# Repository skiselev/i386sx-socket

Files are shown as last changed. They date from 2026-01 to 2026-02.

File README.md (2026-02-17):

# i386sx-socket
386SX Universal Socket Adapter for the [Alsea River 386SX Motherboard](https://github.com/skiselev/mb386sx-rc2016)

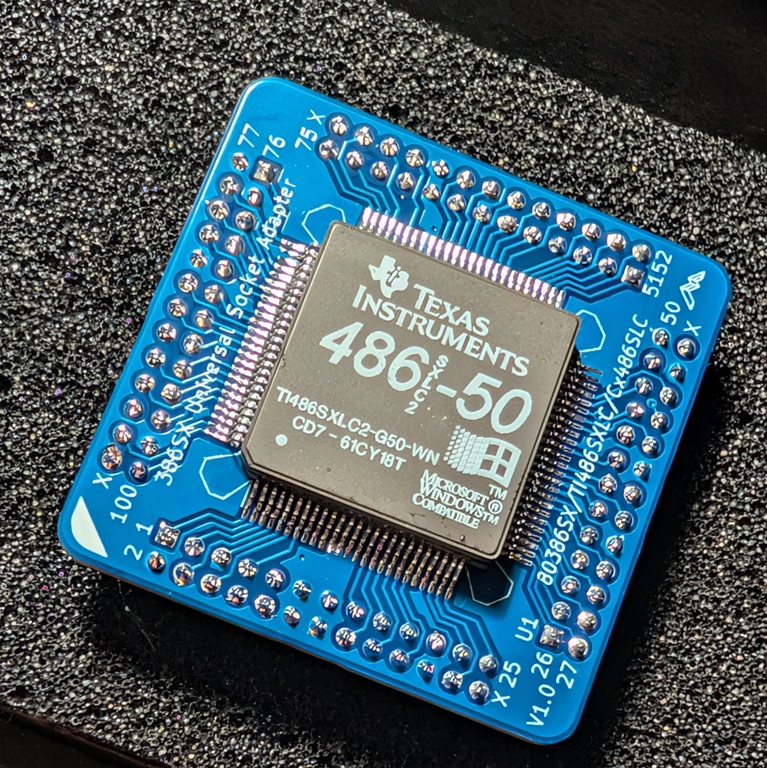
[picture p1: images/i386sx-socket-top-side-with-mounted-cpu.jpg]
386SX Universal Socket Adapter Assembled Board


## Hardware Documentation

### Schematic and PCB Layout

* [Schematic - Version 1.0](KiCad/i386sx-socket-Schematic-1.0.pdf)
* [PCB Layout - Version 1.0](KiCad/i386sx-socket-Board-1.0.pdf)

### Jumpers

#### JP1, JP2 - Bypass the 3.3V Voltage Regulator

Position         | Description
-----------------|--------------------------------------------------------------------------------------------------
Closed (default) | 5V CPU: 5V from the socket is connected to the CPU VCC pins, bypassing the 3.3V voltage regulator
Open             | 3.3V CPU: CPU VCC pins are connected to the 3.3V voltage regulator

#### JP3 - Connect Pin 45 to VCC

Position         | Description
-----------------|--------------------------------------------------------------------------------------------------
1-2              | 5V CPU: Socket pin 45 is connected to the CPU pin 45
Open             | 3.3V CPU: CPU pin 45 is connected to 5V (VCC5 for the 3.3V CPUs)

### Bill of Materials

#### Version 1.0

[386SX Universal Socket Adapter project on Mouser.com](https://www.mouser.com/Tools/Project/Share?AccessID=3e806c1828) - View and order most components except of the CPU, and the PCB.

Component type     | Reference | Description                                          | Quantity | Possible sources and notes 
------------------ | --------- | ---------------------------------------------------- | -------- | --------------------------
PCB                |           | 386SX Universal Socket PCB - Version 1.0             | 1        | Order from a PCB manufacturer of your choice using provided Gerber or KiCad files
Integrated Circuit | U1        | 386SX CPU, TI486SXLC, Cx486SLC CPU, 100 pin BQFP     | 1        | eBay
Integrated Circuit | U2        | NCP1117-3.3, 3.3 V LDO voltge regulator, TO-252-3    | 1        | Mouser [863-NCP1117DT33T5G](https://www.mouser.com/ProductDetail/863-NCP1117DT33T5G). Optional - required for 3.3V CPU
Capacitor          | C1 - C3   | 100 nF, MLCC, 0603 SMD                               | 3        | Mouser [581-KGM15BR71H104JM](https://www.mouser.com/ProductDetail/581-KGM15BR71H104JM). C3 is optional - required for 3.3V CPU
Capacitor          | C4, C5    | 10 uF, MLCC or Tantalum, 1206 SMD                    | 2        | Mouser [963-TMK316BJ106KL-T](https://www.mouser.com/ProductDetail/963-TMK316BJ106KL-T), [74-T55A106M6R3C0200](https://www.mouser.com/ProductDetail/74-T55A106M6R3C0200). Optional - required for 3.3V CPU
Connector          | J1 - J4   | 2x13 pin header, 2 mm pitch                          | 4        | Mouser [538-87758-2616](https://www.mouser.com/ProductDetail/538-87758-2616), [200-MTMM11305LD190](https://www.mouser.com/ProductDetail/200-MTMM11305LD190)

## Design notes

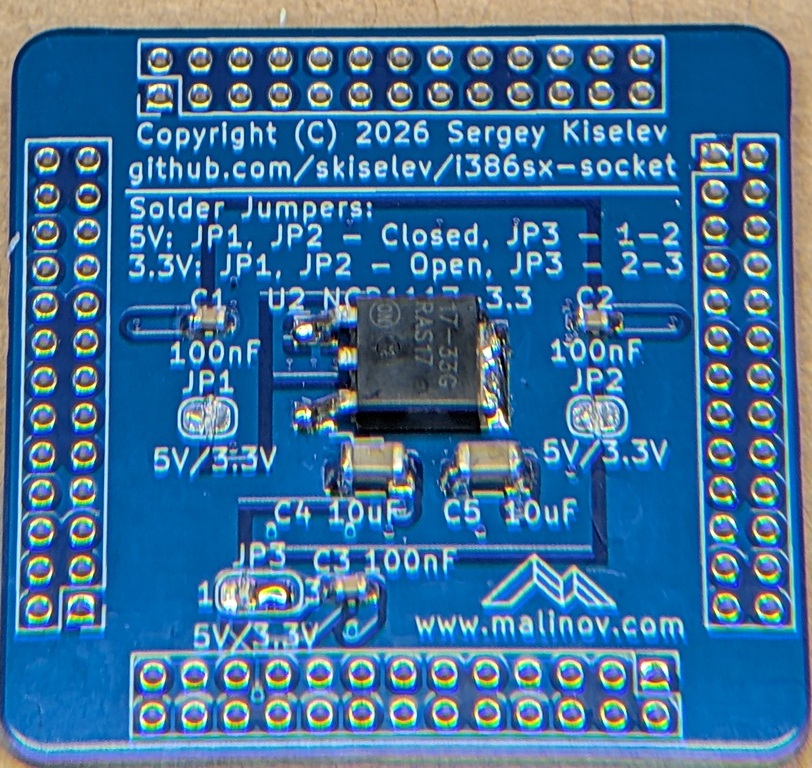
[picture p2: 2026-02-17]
images/i386sx-socket-bottom-side.jpg

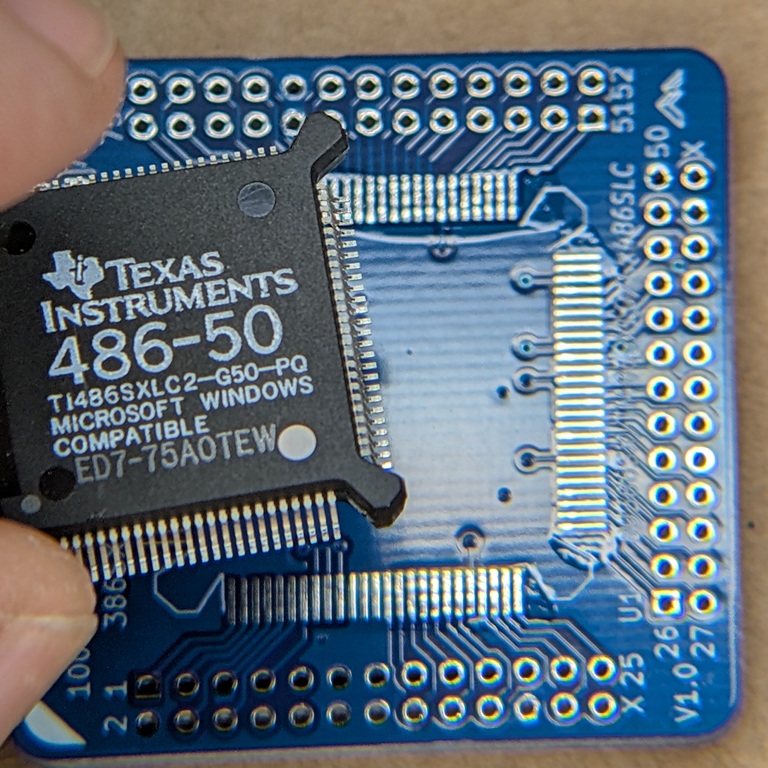
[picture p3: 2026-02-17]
images/i386sx-socket-top-side-with-unmounted-cpu.jpg

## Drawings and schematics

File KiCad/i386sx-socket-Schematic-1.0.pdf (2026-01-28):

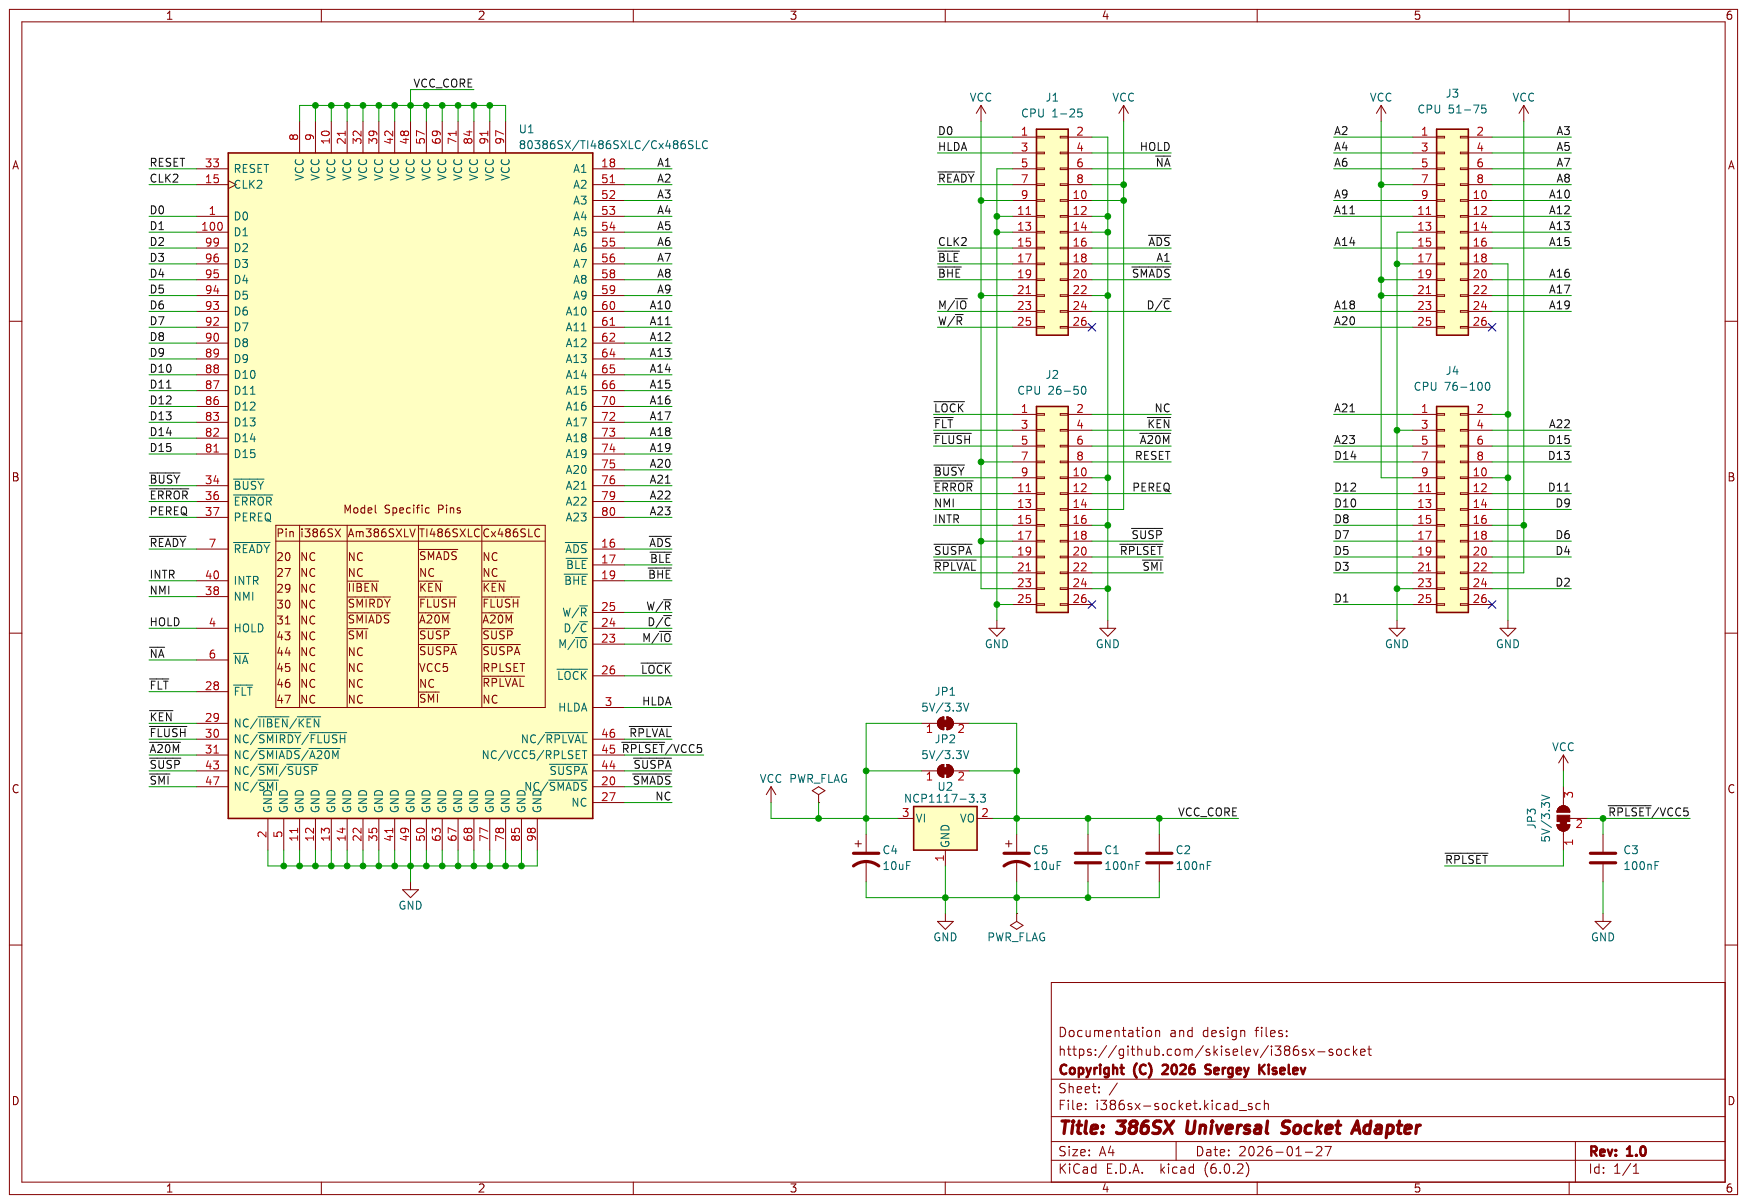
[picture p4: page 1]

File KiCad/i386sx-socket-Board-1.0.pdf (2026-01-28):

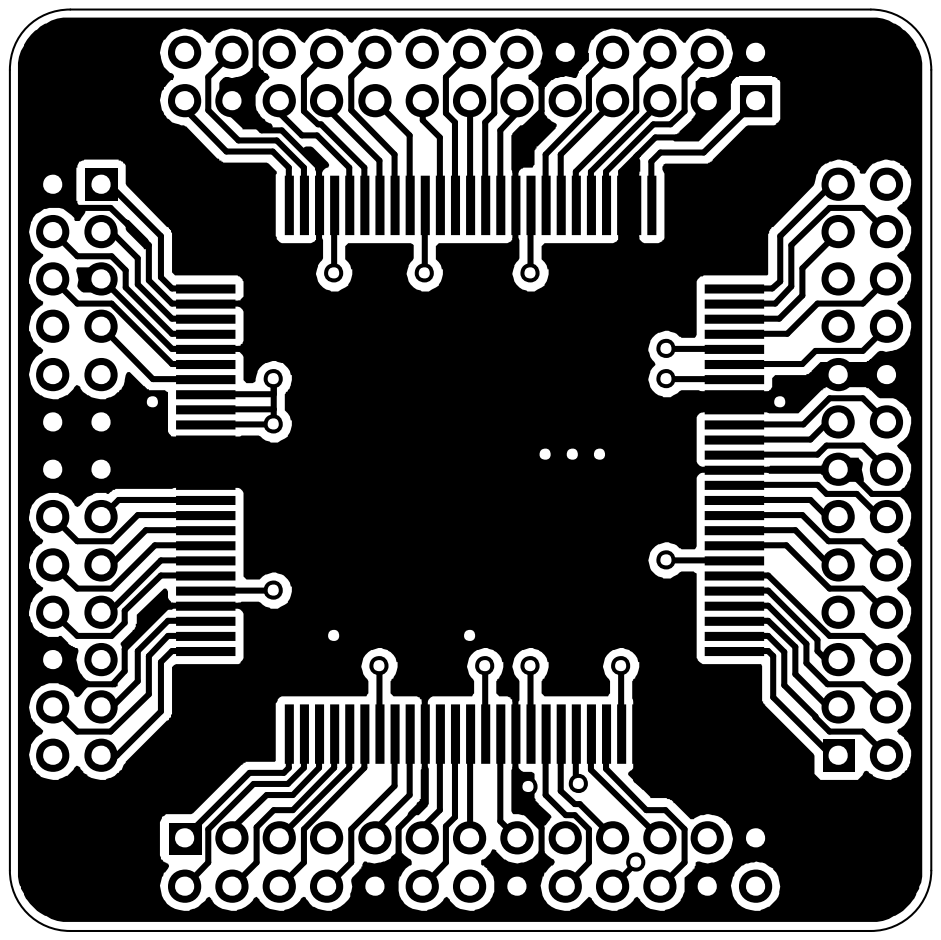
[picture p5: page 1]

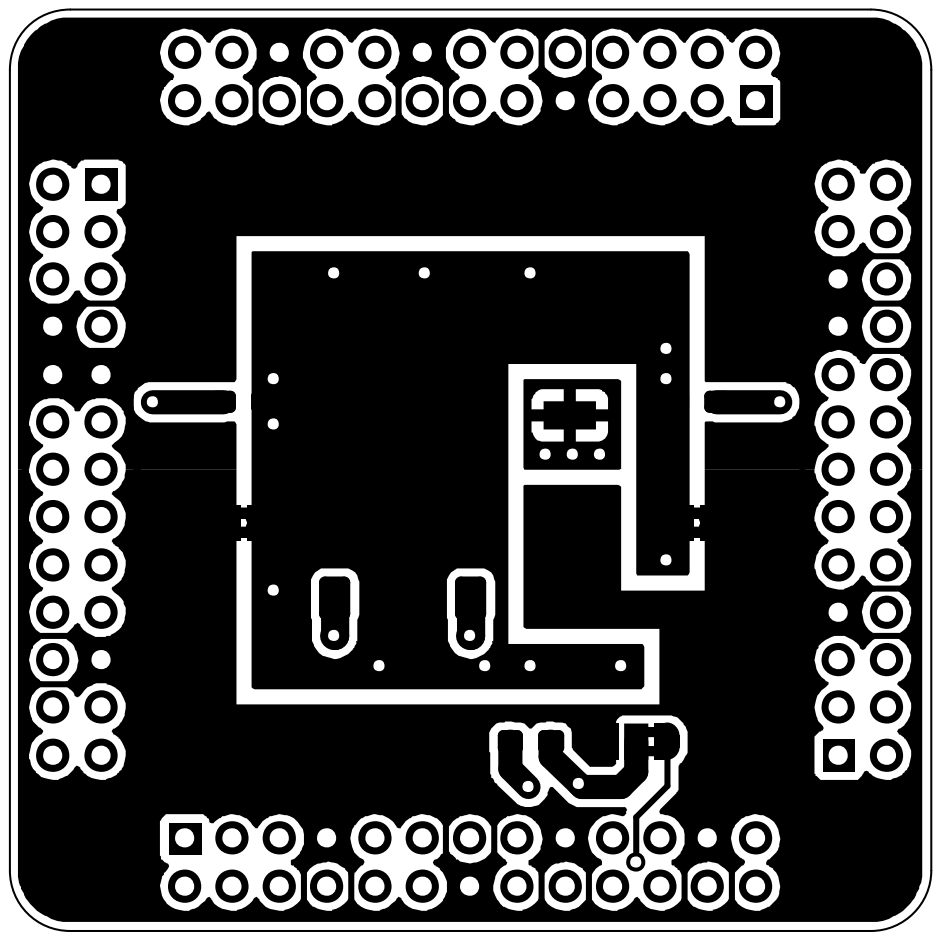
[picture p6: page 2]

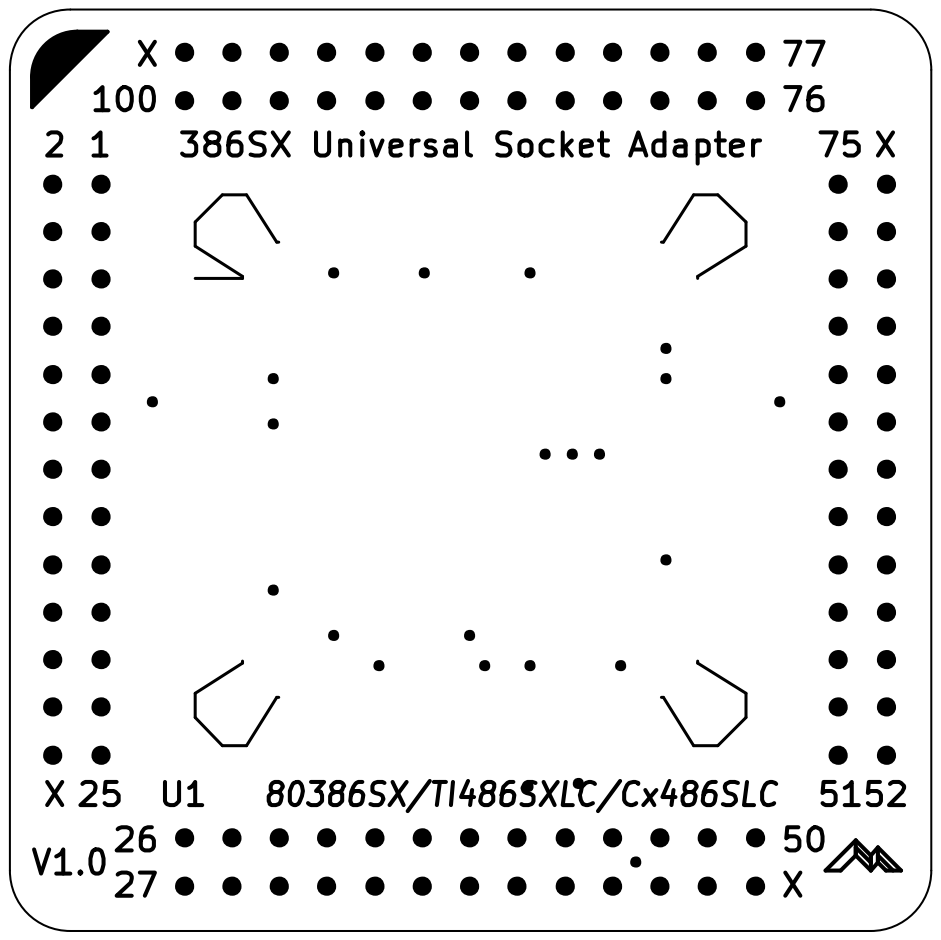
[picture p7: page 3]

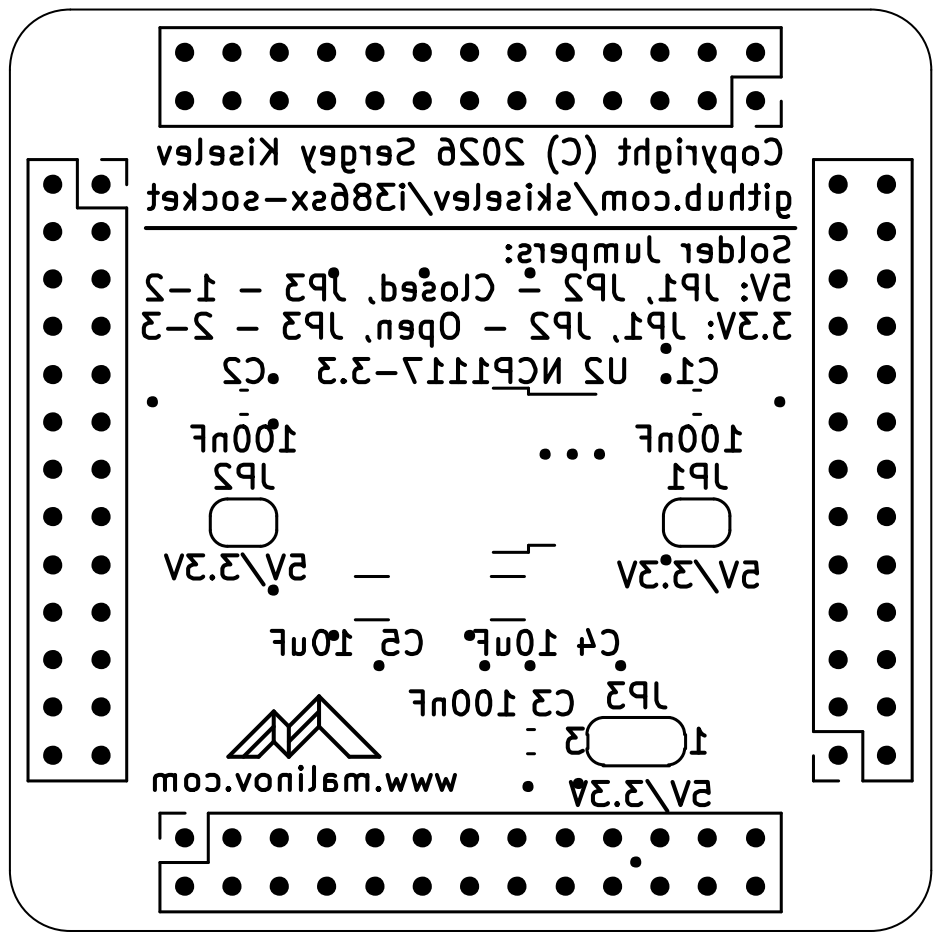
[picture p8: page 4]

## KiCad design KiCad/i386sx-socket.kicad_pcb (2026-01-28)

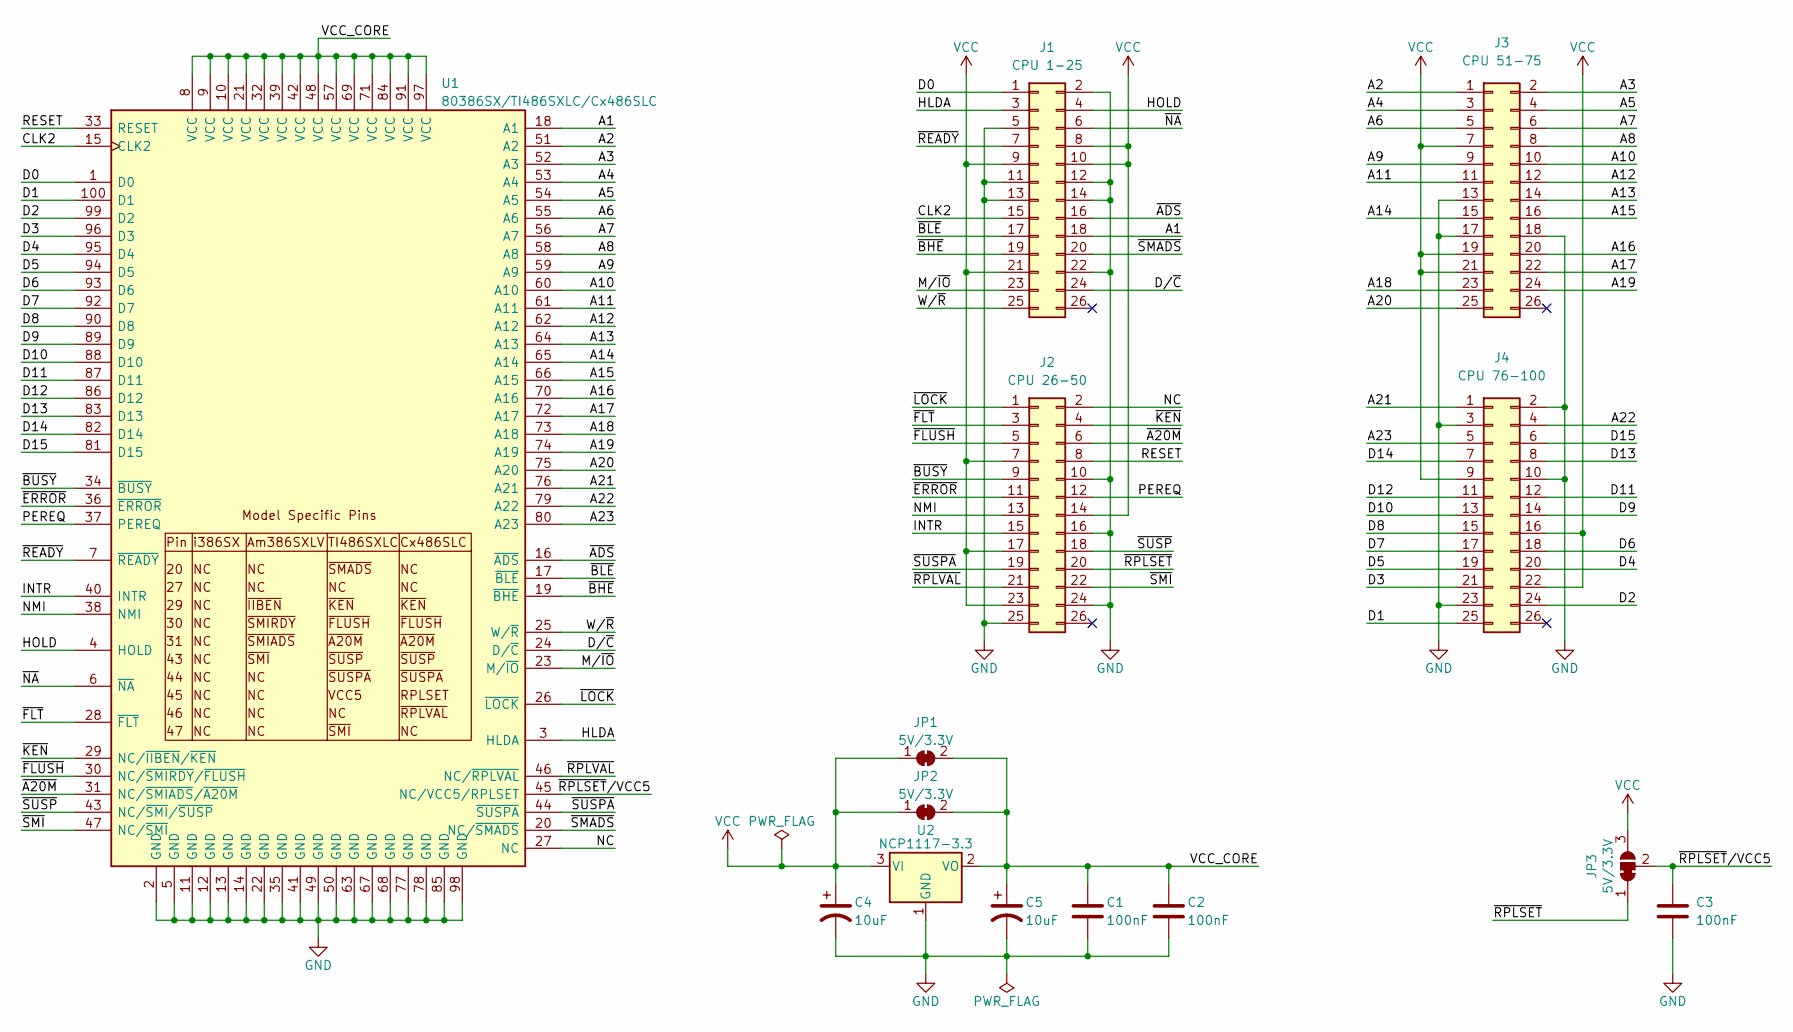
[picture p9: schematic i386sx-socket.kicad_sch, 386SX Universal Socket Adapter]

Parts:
C1, C2, C3: 100nF; C_0603_1608Metric_Pad1.08x0.95mm_HandSolder
C4, C5: 10uF; C_1206_3216Metric_Pad1.33x1.80mm_HandSolder
J1: CPU 1-25; PinHeader_2x13_P2.00mm_Vertical
J2: CPU 26-50; PinHeader_2x13_P2.00mm_Vertical
J3: CPU 51-75; PinHeader_2x13_P2.00mm_Vertical
J4: CPU 76-100; PinHeader_2x13_P2.00mm_Vertical
JP1, JP2: 5V/3.3V; SolderJumper-2_P1.3mm_Bridged2Bar_RoundedPad1.0x1.5mm
JP3: 5V/3.3V; SolderJumper-3_P1.3mm_Bridged2Bar12_RoundedPad1.0x1.5mm_Num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
U1: 80386SX/TI486SXLC/Cx486SLC; PQFP-100_19x19mm_P0.635mm_i386sx
U2: NCP1117-3.3; TO-252-2

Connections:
/A1: J1.18, U1.18 (A1)
/A2: J3.1, U1.51 (A2)
/A3: J3.2, U1.52 (A3)
/A4: J3.3, U1.53 (A4)
/A5: J3.4, U1.54 (A5)
/A6: J3.5, U1.55 (A6)
/A7: J3.6, U1.56 (A7)
/A8: J3.8, U1.58 (A8)
/A9: J3.9, U1.59 (A9)
/A10: J3.10, U1.60 (A10)
/A11: J3.11, U1.61 (A11)
/A12: J3.12, U1.62 (A12)
/A13: J3.14, U1.64 (A13)
/A14: J3.15, U1.65 (A14)
/A15: J3.16, U1.66 (A15)
/A16: J3.20, U1.70 (A16)
/A17: J3.22, U1.72 (A17)
/A18: J3.23, U1.73 (A18)
/A19: J3.24, U1.74 (A19)
/A20: J3.25, U1.75 (A20)
/A21: J4.1, U1.76 (A21)
/A22: J4.4, U1.79 (A22)
/A23: J4.5, U1.80 (A23)
/CLK2: J1.15, U1.15 (CLK2)
/D0: J1.1, U1.1 (D0)
/D1: J4.25, U1.100 (D1)
/D2: J4.24, U1.99 (D2)
/D3: J4.21, U1.96 (D3)
/D4: J4.20, U1.95 (D4)
/D5: J4.19, U1.94 (D5)
/D6: J4.18, U1.93 (D6)
/D7: J4.17, U1.92 (D7)
/D8: J4.15, U1.90 (D8)
/D9: J4.14, U1.89 (D9)
/D10: J4.13, U1.88 (D10)
/D11: J4.12, U1.87 (D11)
/D12: J4.11, U1.86 (D12)
/D13: J4.8, U1.83 (D13)
/D14: J4.7, U1.82 (D14)
/D15: J4.6, U1.81 (D15)
/D/~C: J1.24, U1.24 (D/~C)
/HLDA: J1.3, U1.3 (HLDA)
/HOLD: J1.4, U1.4 (HOLD)
/INTR: J2.15, U1.40 (INTR)
/M/~IO: J1.23, U1.23 (M/~IO)
/NC: J2.2, U1.27 (NC)
/NMI: J2.13, U1.38 (NMI)
/PEREQ: J2.12, U1.37 (PEREQ)
/RESET: J2.8, U1.33 (RESET)
/VCC_CORE: C1.1, C2.1, C5.1, JP1.2 (B), JP2.2 (B), U1.8 (VCC), U1.9 (VCC), U1.10 (VCC), U1.21 (VCC), U1.32 (VCC), U1.39 (VCC), U1.42 (VCC), U1.48 (VCC), U1.57 (VCC), U1.69 (VCC), U1.71 (VCC), U1.84 (VCC), U1.91 (VCC), U1.97 (VCC), U2.2 (VO)
/W/~R: J1.25, U1.25 (W/~R)
/~A20M: J2.6, U1.31 (NC/~SMIADS/~A20M)
/~ADS: J1.16, U1.16 (~ADS)
/~BHE: J1.19, U1.19 (~BHE)
/~BLE: J1.17, U1.17 (~BLE)
/~BUSY: J2.9, U1.34 (~BUSY)
/~ERROR: J2.11, U1.36 (~ERROR)
/~FLT: J2.3, U1.28 (~FLT)
/~FLUSH: J2.5, U1.30 (NC/~SMIRDY/~FLUSH)
/~KEN: J2.4, U1.29 (NC/~IIBEN/~KEN)
/~LOCK: J2.1, U1.26 (~LOCK)
/~NA: J1.6, U1.6 (~NA)
/~READY: J1.7, U1.7 (~READY)
/~RPLSET: J2.20, JP3.1 (A)
/~RPLSET/VCC5: C3.1, JP3.2 (C), U1.45 (NC/VCC5/RPLSET)
/~RPLVAL: J2.21, U1.46 (NC/~RPLVAL)
/~SMADS: J1.20, U1.20 (NC/~SMADS)
/~SMI: J2.22, U1.47 (NC/~SMI)
/~SUSPA: J2.19, U1.44 (~SUSPA)
/~SUSP: J2.18, U1.43 (NC/~SMI/~SUSP)
GND: C1.2, C2.2, C3.2, C4.2, C5.2, J1.2, J1.5, J1.11, J1.12, J1.13, J1.14, J1.22, J2.10, J2.16, J2.24, J2.25, J3.13, J3.17, J3.18, J4.2, J4.3, J4.10, J4.23, U1.2 (GND), U1.5 (GND), U1.11 (GND), U1.12 (GND), U1.13 (GND), U1.14 (GND), U1.22 (GND), U1.35 (GND), U1.41 (GND), U1.49 (GND), U1.50 (GND), U1.63 (GND), U1.67 (GND), U1.68 (GND), U1.77 (GND), U1.78 (GND), U1.85 (GND), U1.98 (GND), U2.1 (GND)
VCC: C4.1, J1.8, J1.9, J1.10, J1.21, J2.7, J2.14, J2.17, J2.23, J3.7, J3.19, J3.21, J4.9, J4.16, J4.22, JP1.1 (A), JP2.1 (A), JP3.3 (B), U2.3 (VI)

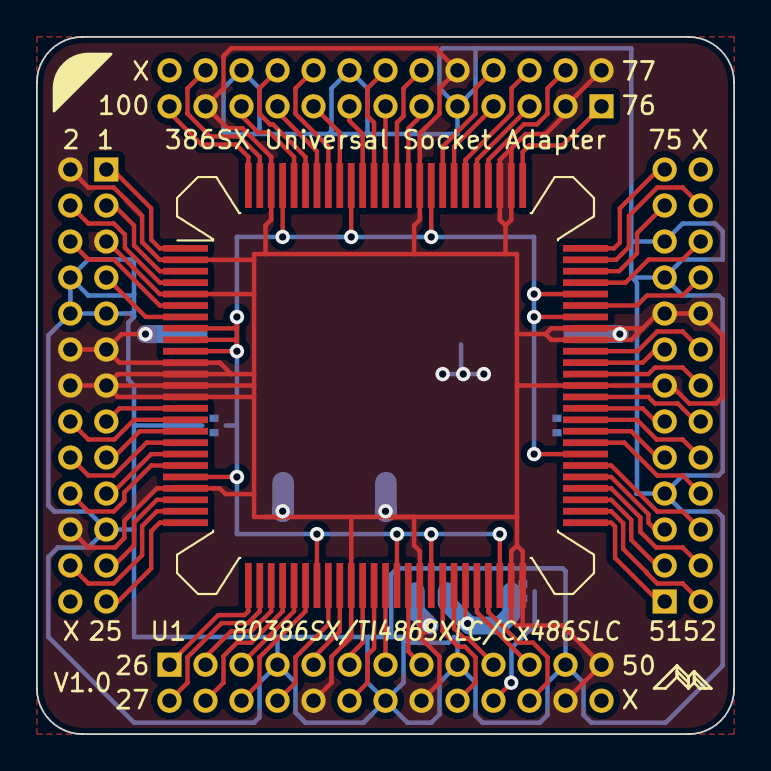
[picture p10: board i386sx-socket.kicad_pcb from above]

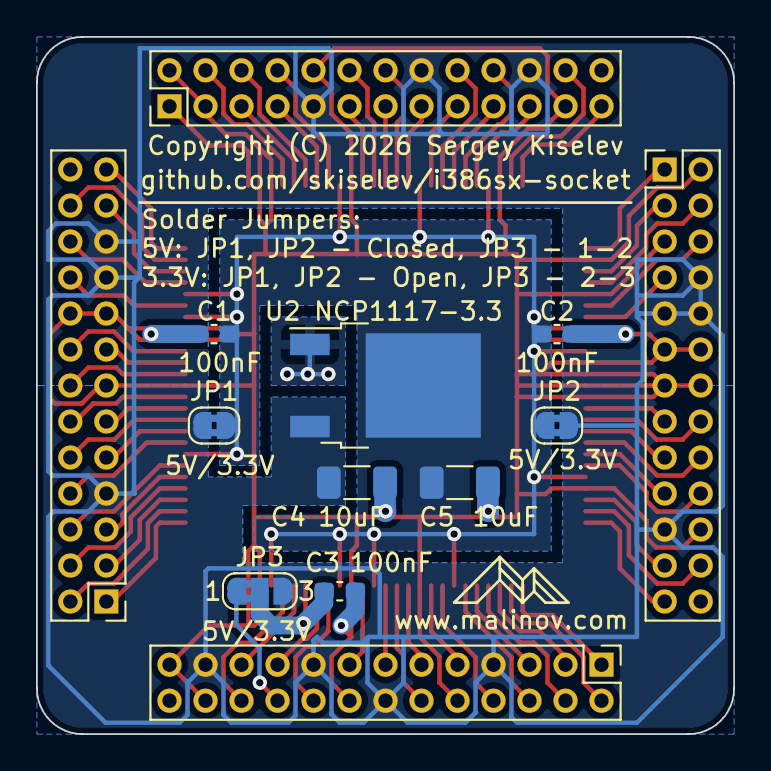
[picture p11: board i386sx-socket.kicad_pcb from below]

Board: 2 copper layers, 38.7 x 38.7 mm, 14 parts (13 on the bottom side), 72 nets.

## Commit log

2026-01-28 Add version 1.0 files
    [i386sx-socket-B_Cu.gbr, i386sx-socket-B_Mask.gbr, i386sx-socket-B_Paste.gbr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]
2026-01-28 Make PCB slightly larger so that zones connect on the outside edge
    [i386sx-socket-B_Cu.gbr, i386sx-socket-B_Mask.gbr, i386sx-socket-B_Paste.gbr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]
2026-02-17 README: Update links in the BoM

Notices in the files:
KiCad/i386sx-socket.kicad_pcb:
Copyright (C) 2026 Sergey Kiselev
